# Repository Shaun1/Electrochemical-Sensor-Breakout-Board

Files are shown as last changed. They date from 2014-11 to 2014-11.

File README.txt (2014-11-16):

---------------	LICENCE:

This work is licensed under the Creative Commons Attribution 4.0 International License. To view a copy of this license, visit http://creativecommons.org/licenses/by/4.0/.

You are free to:

Share — copy and redistribute the material in any medium or format
Adapt — remix, transform, and build upon the material
for any purpose, even commercially.
The licensor cannot revoke these freedoms as long as you follow the license terms.

Terms:

Attribution — You must give appropriate credit, provide a link to the license, and indicate if changes were made. You may do so in any reasonable manner, but not in any way that suggests the licensor endorses you or your use.

No additional restrictions — You may not apply legal terms or technological measures that legally restrict others from doing anything the license permits.

All design files for BLE Electrochemical Sensor are provided as-is.

Please credit Houlihan Engineering & Design / www.hedlabs.com if you reproduce this work or create a derivative work.

---------------	CONTENTS:

Electrochemical Sensor Breakout Board.dch
	(DipTrace Schematic)

Electrochemical Sensor Breakout Board.dip
	(DipTrace Board Layout)

Electrochemical Sensor Breakout Board.asc
	(DipTrace ASCII Schemaitic)

Electrochemical Sensor Breakout Board.pcb
	(P-Cad ASCII Board Layout)

Electrochemical Sensor Breakout Board.pdf
	(PDF Schematic)

ECSBB BOM.csv
	(Bill of Materials)

MFG
	(Folder containing Gerber files, Drill file, and Pick and Place CSV file)

---------------	USE:

These files were created using DipTrace, a powerful and low-cost ECAD system. A non-profit free version of DipTrace can be downloaded at http://www.diptrace.com. If you use a different ECAD system, ASCII files are provided for import to other software packages. 3rd-party conversion utilities may be needed depending on the system you are importing to.

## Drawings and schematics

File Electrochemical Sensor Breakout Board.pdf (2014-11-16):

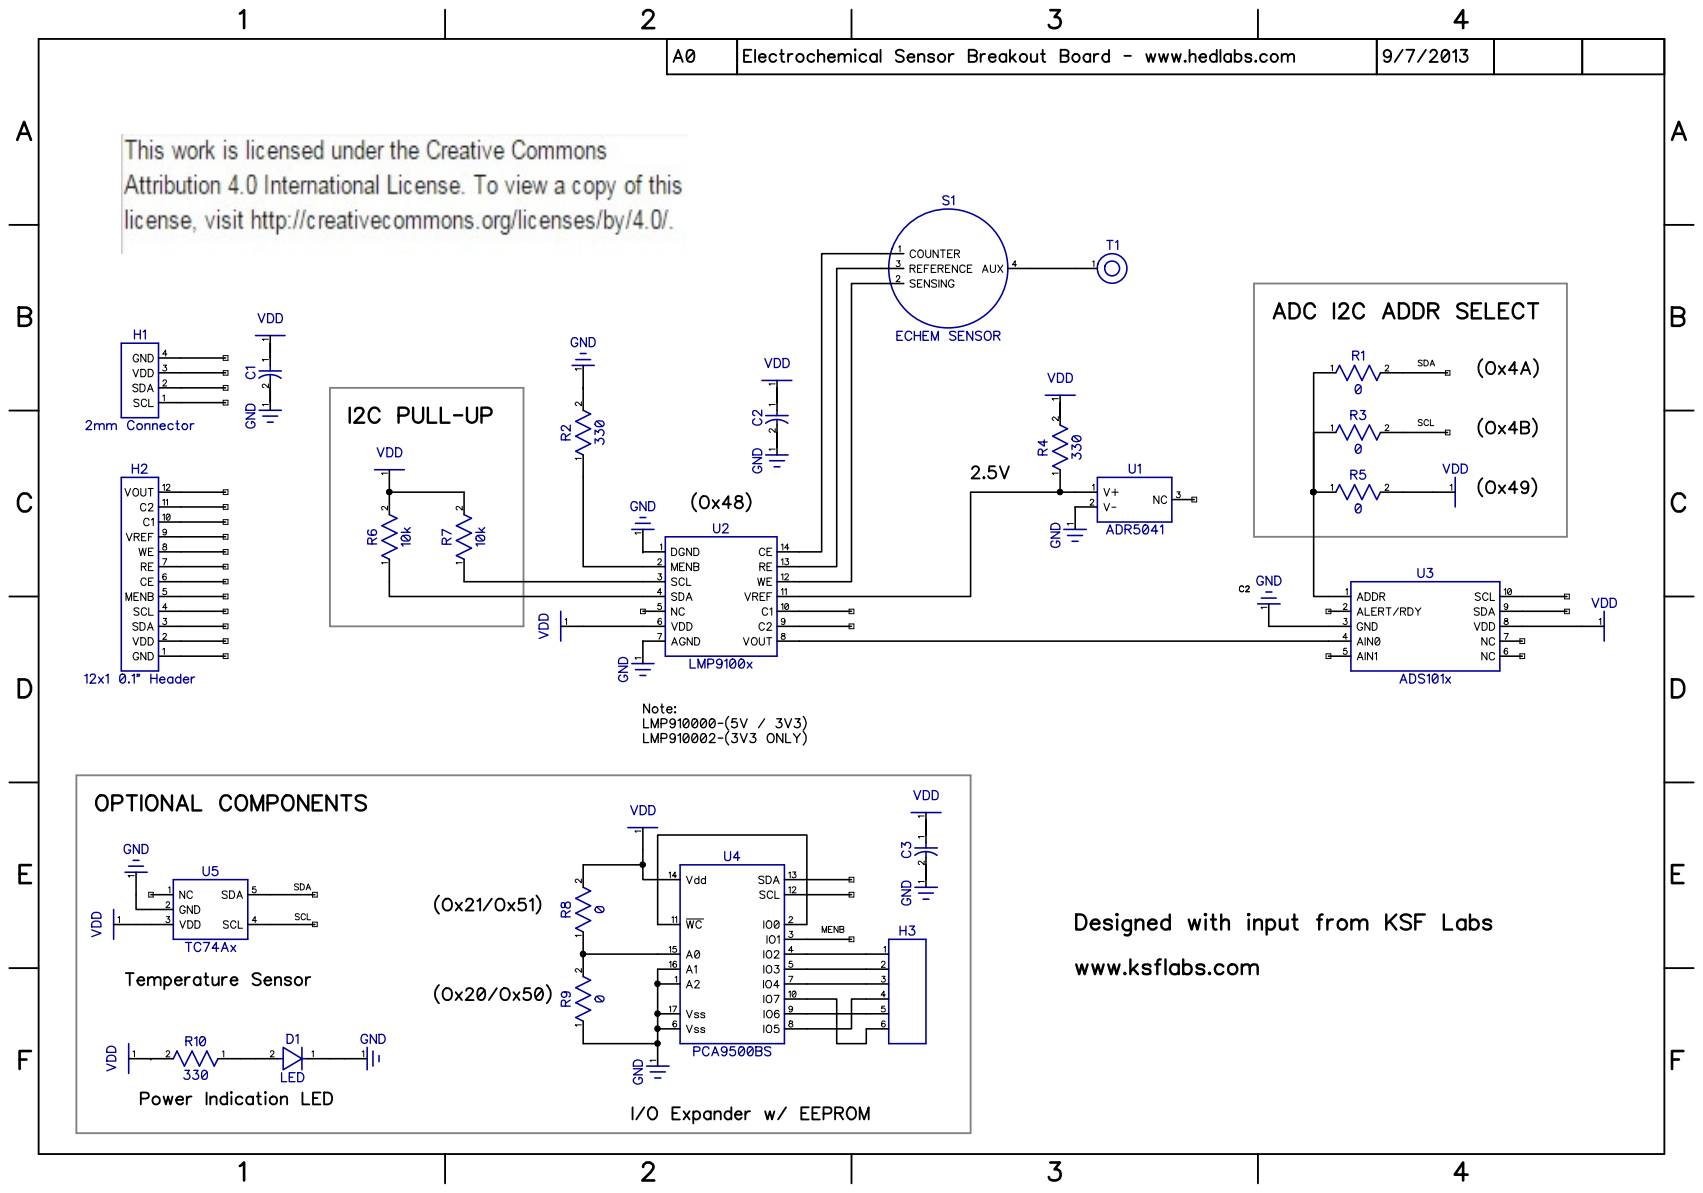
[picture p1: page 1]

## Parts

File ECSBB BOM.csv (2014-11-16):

# | RefDes | Name | Value | Pattern | Quantity | Description
1 | C1 | CAP_0603 | 10uF | CAP_0603 | 1
2 | C2, C3 | CAP_0402 | 0.1uF | CAP_0402 | 2
3 | D1 | DIODE_0805 | Green LED | DIO_0805 | 1
4 | H1 | GROVE |  | GROVE | 1 | Seeed Studio GROVE Connector
5 | H2 | 12x1 0.1 Header |  | 12x1 0.1 | 1
6 | H3 | 6x1 0.1 Header |  | 6x1 0.1 | 1
7 | R1, R3, R5, R8, R9 | RES_0603 | 0 | RES_0603 | 5 | Jumper Resistors for I2C Addr Selection
8 | R2, R4, R10 | RES_0603 | 330 | RES_0603 | 3
9 | R6, R7 | RES_0603 | 10k | RES_0603 | 2
10 | S1 | R530-0403-02N-440P55-R27-L14 |  | Varies | 1 | SGX Sensor Socket from Andon Electronics
11 | T1 | Test Point |  | 1 Pin | 0
12 | U1 | ADR5041 | 2.5V | SOT323 | 1 | 2.5v shunt
13 | U2 | LMP9100x |  | LMP91002 | 1 | Analog Front End
14 | U3 | ADS101x |  | PRQFN-10RNP/1.6x2.1x0.5 | 1
15 | U4 | PCA9500BS |  | QFN-16/4x4x0.65 | 1
16 | U5 | TC74Ax |  | SOT23-5 | 1
 |  |  |  |  | 24

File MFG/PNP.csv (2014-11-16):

RefDes | Name | X (in) | Y (in) | Side | Rotate | Value
D1 | DIODE_0805 | 2.025 | 0.907 | Top | 90 | LED
H1 | GROVE | 2.275 | 0.5 | Top | 90 | 2mm Connector
H2 | 12Pin | 1.075 | 0.051 | Top | 180 | 12x1 0.1 Header
H3 | 6Pin | 0.781 | 0.95 | Top | 180
R1 | RES_0603 | 1.875 | 0.867 | Top | 270 | 0
R2 | RES_0603 | 1.608 | 0.45 | Top | 0 | 330
R3 | RES_0603 | 1.8 | 0.867 | Top | 270 | 0
R4 | RES_0603 | 1.05 | 0.533 | Top | 270 | 330
R5 | RES_0603 | 1.725 | 0.867 | Top | 270 | 0
R6 | RES_0603 | 1.609 | 0.3 | Top | 0 | 10k
R7 | RES_0603 | 1.609 | 0.375 | Top | 0 | 10k
R8 | RES_0603 | 1.625 | 0.867 | Top | 270 | 0
R9 | RES_0603 | 1.55 | 0.867 | Top | 90 | 0
R10 | RES_0603 | 2.112 | 0.917 | Top | 270 | 330
S1 | ECHEM SENSOR | 0.576 | 0.487 | Top | 270
U1 | ADR5041 | 1.081 | 0.674 | Top | 90 | 2.5V
U2 | LMP9100x | 1.2 | 0.259 | Top | 90
U3 | ADS101x | 1.389 | 0.417 | Top | 270
U4 | PCA9500BS | 1.287 | 0.789 | Top | 270
U5 | TC74Ax | 1.177 | 0.519 | Top | 0
C2 | CAP_0402 | 1.355 | 0.287 | Top | 0 | 0.1uF
C3 | CAP_0402 | 1.432 | 0.95 | Top | 180 | 0.1uF
C1 | CAP_0603 | 2.12 | 0.746 | Top | 180 | 10uF
